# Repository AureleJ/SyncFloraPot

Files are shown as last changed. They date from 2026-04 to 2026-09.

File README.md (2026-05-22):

# 🪴 SyncFloraPot





**SyncFloraPot** is an end-to-end IoT ecosystem designed for smart plant care. It combines custom embedded firmware, a scalable backend, and a cross-platform mobile application to provide real-time monitoring and automated watering.

🔗 **Detailed Project Overview:** [aurelejoblet.com/project/syncflorapot](https://aurelejoblet.com/project/syncflorapot)

---

## 🚀 Overview

SyncFloraPot isn't just a smart pot, it's a complete monitoring solution. It tracks soil moisture, ambient temperature, and light levels, allowing users to interact with their plants through a dedicated mobile interface.

### Key Features
- **Real-time Data:** Live sensor feedback via MQTT/WebSockets.
- **Automated Irrigation:** Smart watering logic based on soil moisture thresholds.
- **Cross-Platform Control:** Monitor your plants from anywhere using the mobile app.
---

## 🛠 Technical Stack & Architecture

### 📁 [Firmware](./firmware)
* **Hardware:** ESP32 Microcontroller.
* **Framework:** ESP-IDF.
* **Sensors:** Capacitive soil moisture sensor, DHT22 (Temp/Hum), Light intensity sensor.
* **Communication:** Wi-Fi, MQTT protocol.

### 📁 [Client](./client)
* **Framework:** React Native / Expo.
* **Features:** Real-time dashboards, push notifications for low water levels, and manual override controls.

### 📁 [Backend](./backend)
* **Environment:** Node.js.
* **Database:** MongoDB/PostgreSQL for historical data logging.
* **Communication:** Integrated MQTT Broker for hardware-to-cloud messaging.

---

## 📂 Directory Structure

```txt
SyncFloraPot/
├── firmware/   # ESP32 Firmware code (ESP-IDF)
├── client/     # Mobile application (Android/iOS)
└── backend/    # Server logic and database management

```

---

## 🔧 Installation & Setup

1. **Clone the repo:**
```bash
git clone [https://github.com/AureleJ/SyncFloraPot.git](https://github.com/AureleJ/SyncFloraPot.git)

```

2. **Firmware:** Navigate to `/firmware` and follow the `idf.py build` instructions.
3. **Mobile App:** Run `npm install` in `/client` then `npx expo start`.
4. **Backend:** Configure your `.env` in `/backend` and run `npm start`.

---

## 👤 Author

**Aurèle Joblet** Engineering Student at ESIEA | Embedded Systems & Software Development

🌐 [Portfolio](https://aurelejoblet.com) | [LinkedIn](https://www.google.com/search?q=https://www.linkedin.com/in/aurele-joblet/)

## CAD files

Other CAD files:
hardware/WaterPot.f3z

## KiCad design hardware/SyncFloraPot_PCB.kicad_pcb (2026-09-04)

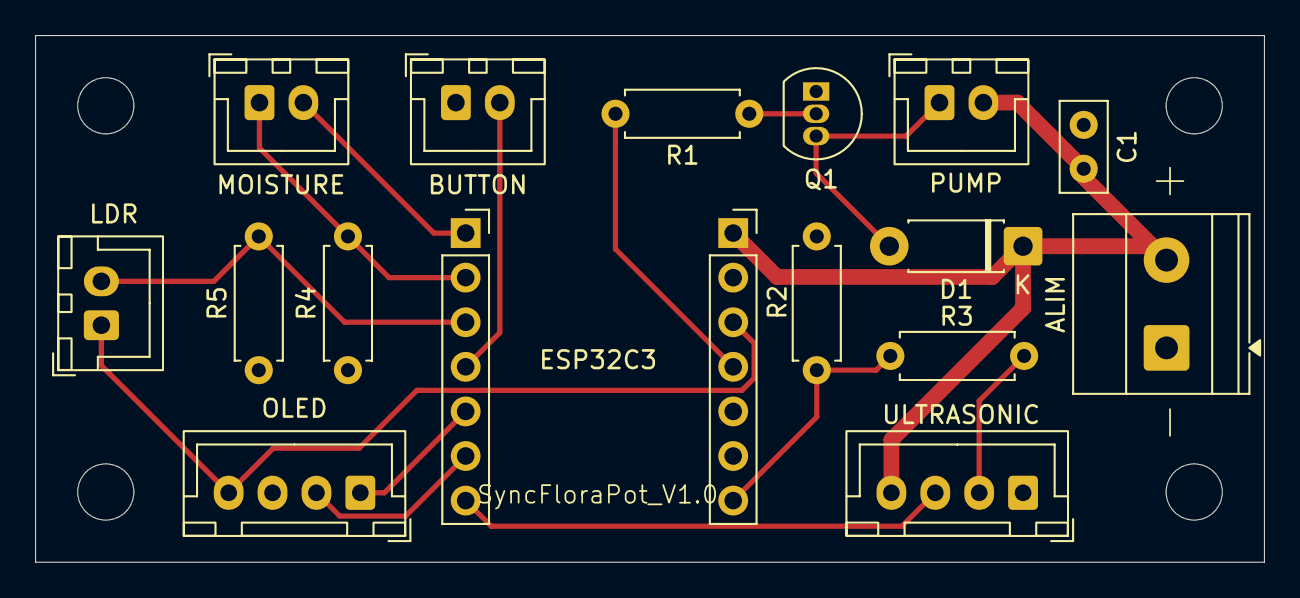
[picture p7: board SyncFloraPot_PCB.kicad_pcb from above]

Board: 2 copper layers, 70.0 x 30.0 mm, 21 parts (0 on the bottom side), 15 nets.

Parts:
ALIM: Screw_Terminal_01x02; TerminalBlock_Phoenix_MKDS-1,5-2_1x02_P5.00mm_Horizontal
BUTTON: Conn_01x02; JST_XH_B2B-XH-A_1x02_P2.50mm_Vertical
C1: 100nF; C_Disc_D5.0mm_W2.5mm_P2.50mm
D1: D; D_DO-41_SOD81_P7.62mm_Horizontal
H1, H2, H3, H4: MountingHole; MountingHole_3.2mm_M3_ISO7380
J_ESP_L1: Conn_01x07; PinSocket_1x07_P2.54mm_Vertical
J_ESP_R1: Conn_01x07; PinSocket_1x07_P2.54mm_Vertical
LDR: Conn_01x02; JST_XH_B2B-XH-A_1x02_P2.50mm_Vertical
MOISTURE: Conn_01x02; JST_XH_B2B-XH-A_1x02_P2.50mm_Vertical
OLED: Conn_01x04; JST_XH_B4B-XH-A_1x04_P2.50mm_Vertical
PUMP: Conn_01x02; JST_XH_B2B-XH-A_1x02_P2.50mm_Vertical
Q1: Q_NPN_EBC; TO-92_Inline
R1, R2: 1k; R_Axial_DIN0207_L6.3mm_D2.5mm_P7.62mm_Horizontal
R3: 510; R_Axial_DIN0207_L6.3mm_D2.5mm_P7.62mm_Horizontal
R4, R5: 10k; R_Axial_DIN0207_L6.3mm_D2.5mm_P7.62mm_Horizontal
ULTRASONIC: Conn_01x04; JST_XH_B4B-XH-A_1x04_P2.50mm_Vertical

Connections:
+3V3: J_ESP_R1.3, LDR.1, OLED.4
+5V: ALIM.2, C1.1, D1.1 (K), J_ESP_R1.1, PUMP.2, ULTRASONIC.4
GND: ALIM.1, BUTTON.1, C1.2, J_ESP_R1.2, OLED.3, Q1.1 (E), R2.2, R4.1, R5.1, ULTRASONIC.1
unnamed: D1.2 (A), PUMP.1, Q1.3 (C)
unnamed: BUTTON.2, J_ESP_L1.4
unnamed: J_ESP_L1.1, MOISTURE.2
unnamed: J_ESP_L1.2, MOISTURE.1, R4.2
unnamed: J_ESP_L1.3, LDR.2, R5.2
unnamed: J_ESP_L1.5, OLED.1
unnamed: J_ESP_L1.6, OLED.2
unnamed: J_ESP_L1.7, ULTRASONIC.3
unnamed: J_ESP_R1.4, R1.2
unnamed: J_ESP_R1.7, R2.1, R3.2
unnamed: R3.1, ULTRASONIC.2
unnamed: Q1.2 (B), R1.1

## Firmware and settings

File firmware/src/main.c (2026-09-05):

#include "freertos/FreeRTOS.h"
#include "freertos/task.h"
#include "esp_log.h"
#include "freertos/queue.h"

#include "config.h"

#include "core/system_state.h"
#include "core/sensor_state.h"
#include "network/wifi_manager.h"
#include "drivers/i2c_manager/i2c_manager.h"
#include "drivers/adc_manager/adc_manager.h"

#include "core/message.h"

#include "services/srv_display.h"
#include "services/srv_button.h"
#include "services/srv_monitoring.h"
#include "services/srv_hydration.h"
#include "services/srv_internet.h"

static const char *TAG = "MAIN";

void app_main(void)
{
    ESP_LOGI(TAG, "Start");

    system_state_init();
    sensor_state_init();
    wifi_manager_init();
    i2c_manager_init();
    ESP_ERROR_CHECK(adc_manager_init());
    
    srv_button_init();
    srv_display_init();
    srv_monitoring_init();
    srv_hydration_init();
    srv_internet_init();

    ESP_LOGI(TAG, "Success");
}

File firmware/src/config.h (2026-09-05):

#ifndef CONFIG_H
#define CONFIG_H

#include "driver/gpio.h"
#include "hal/adc_types.h"

// ADC channels
#define MOISTURE_ADC_CHANNEL GPIO_NUM_3
#define LDR_ADC_CHANNEL GPIO_NUM_4

// GPIO pins
#define SDA_PIN GPIO_NUM_6
#define SCL_PIN GPIO_NUM_7 
#define MOISTURE_POWER_GPIO GPIO_NUM_2
#define PUMP_GPIO_PIN GPIO_NUM_10
#define ULTRASONIC_ECHO_PIN GPIO_NUM_20
#define ULTRASONIC_TRIG_PIN GPIO_NUM_21
#define BUTTON_GPIO_PIN GPIO_NUM_5

// Thresholds
#define LDR_NIGHT_THRESHOLD 15
#define MOISTURE_DRY_THRESHOLD 5
#define MOISTURE_HALF_DRY_THRESHOLD 15
#define WATER_LEVEL_MIN_THRESHOLD 4.5f
#define WATER_LEVEL_MAX_THRESHOLD 1.5f

// Timings
#define MONITORING_INTERVAL_MS 1000 // Interval between sensor readings

#endif // CONFIG_H

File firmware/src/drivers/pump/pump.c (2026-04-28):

#include "pump.h"
#include "esp_log.h"

static const char *TAG = "PUMP_DRIVER";
static gpio_num_t pump_pin = -1;
static bool s_initialized = false;

int last_activation_time = 0;

esp_err_t pump_init(gpio_num_t pump_pin_arg)
{
    pump_pin = pump_pin_arg;

    esp_err_t ret = gpio_set_direction(pump_pin, GPIO_MODE_OUTPUT);
    if (ret != ESP_OK)
    {
        ESP_LOGE(TAG, "Failed to set pump pin direction: %s", esp_err_to_name(ret));
        return ret;
    }

    ret = gpio_set_level(pump_pin, 0);
    if (ret != ESP_OK)
    {
        ESP_LOGE(TAG, "Failed to set pump pin level: %s", esp_err_to_name(ret));
        return ret;
    }

    s_initialized = true;

    return ESP_OK;
}

esp_err_t pump_on()
{
    if (!s_initialized)
    {
        ESP_LOGE(TAG, "Pump not initialized");
        return ESP_ERR_INVALID_STATE;
    }

    esp_err_t ret = gpio_set_level(pump_pin, 1);
    if (ret != ESP_OK)
    {
        ESP_LOGE(TAG, "Failed to turn pump on: %s", esp_err_to_name(ret));
        return ret;
    }

    return ESP_OK;
}

esp_err_t pump_off()
{
    if (!s_initialized)
    {
        ESP_LOGE(TAG, "Pump not initialized");
        return ESP_ERR_INVALID_STATE;
    }

    esp_err_t ret = gpio_set_level(pump_pin, 0);
    if (ret != ESP_OK)
    {
        ESP_LOGE(TAG, "Failed to turn pump off: %s", esp_err_to_name(ret));
        return ret;
    }

    return ESP_OK;
}

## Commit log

2026-04-12 Add LDR and Moisture sensors gestion with adc manager
2026-04-12 Passing ADC channels as parameters, improve error gestion
    [ldr.c, moisture.c]
2026-04-12 Adding ultrasonic sensor
2026-04-21 Add I2C manager and OLED display drivers
2026-04-21 Add basic pump driver
2026-04-23 Refactor UI engine into modular UI
    Replace the monolithic drivers/display UI engine with a modular UI library.
2026-04-24 Rename UI framework in DianUI and add comments
2026-04-28 Improve LDR ADC reading accuracy
2026-04-28 Improve LDR ADC reading accuracy and add power control pin
2026-04-30 Add thread-safe sensor_state
    Introduce a new sensor_state module to hold plant sensor data with thread-safe access. Provides initialization, update functions for light, water, soil, and pump state, plus sensor_state_get_copy() t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
2026-04-30 Add plant_data_t
    Represent plant sensors values and actuators state.
2026-04-30 Add hydration message
    Represents hydration command for pump
2026-04-30 Add monitoring, display, internet, hydration
    Add new service tasks for monitoring, display, internet and hydration. srv_monitoring reads sensors, updates sensor_state, sends watering commands to the hydration queue when soil is low, and notifie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
2026-08-10 Add new driver for button
    Small driver to integrate buttons
2026-08-10 Add button service task
2026-08-31 Add DianUI time singleton
    Include getters for frame delta time and elapsed milliseconds
2026-09-02 Refactor button service to emit press events
2026-09-04 Add DianUI screen views and navigation flow
2026-09-04 Add SyncFloraPot PCB design files
    [SyncFloraPot_PCB.kicad_pcb, SyncFloraPot_PCB.kicad_sch, WaterPot.f3z]
2026-09-05 Add custom partitions and warnings for compilation
    [partitions.csv]
2026-10-04 Replace Material theme with custom design
2026-10-25 Update home view water and time display
    Replace the Wi-Fi icon and sensor text labels with water-level drop indicators, display the current local time, and use configured sensor thresholds for face emotions.
